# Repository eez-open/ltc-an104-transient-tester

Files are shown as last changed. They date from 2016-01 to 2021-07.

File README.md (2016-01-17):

LTC [AN104](http://www.linear.com/docs/29876) Closed loop load transient tester Eagle, Gebgers and BOM. It could be used for testing various LDOs, power supplies, etc.
Two PCB variants are available: 

* with power supply (ac-powered) that can be housed e.g. into Hammond diecast aluminium enclosure HM-1590U 
* without power supply (dc-powered) using two external 15 VDC sources connected with 2.1/5.5 mm DC plugs.

**Please note that max. allowed D.U.T voltage is determined with switching transistor SOA.**

**********************

Repository: www.github.com/eez-open
Web site: www.envox.hr/eez

**********************

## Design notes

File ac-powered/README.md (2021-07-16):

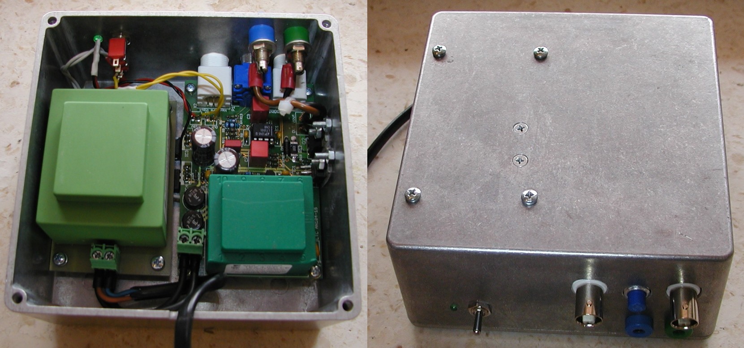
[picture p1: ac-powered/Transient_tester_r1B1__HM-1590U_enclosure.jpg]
Transient tester assembled


LTC [AN104](https://www.analog.com/media/en/technical-documentation/application-notes/an104f.pdf) Closed loop load transient tester (with on board power supply) 

**Please note that max. allowed D.U.T voltage is determined with switching transistor SOA.**

**********************

Repository: www.github.com/eez-open
Web site: www.envox.hr/eez

**********************

*EEZ 2-layer (+tKeepout +_tNames) *job script is used for generating Gerber files. Use [gerbv](http://gerbv.geda-project.org/), a free/open source Gerber viewer to inspect generated files.

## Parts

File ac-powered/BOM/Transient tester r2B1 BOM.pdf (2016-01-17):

LTC AN104 closed loop load transient tester with power supply (PCB: r2B1, 2016-10-16)

1,305
Farnell | TME
2 | B125R-DIO | | B1, B2 | 1861434 | 0,227 | £0,45 | B125R-DIO | 0,157 | 0,31 € | 0,31 €
4 | 100n | | C1, C2, C4, C5 | 1141777 | 0,072 | £0,29 | CM-100N-X7R | 0,038 | 0,15 € | 0,15 €
2 | 1u | | C3, C7 | 2112910 | 0,186 | £0,37 | C340C105K1R5TA | 0,214 | 0,43 € | 0,43 €
1 | 10n | | C6 | 1005991 | 0,556 | £0,56 | FKS2-10N/100 | 0,079 | 0,08 € | 0,08 €
2 | 1mF/25V | | C8, C11 | 1800654 | 0,368 | £0,74 | RD1E108M10020BB | 0,161 | 0,32 € | 0,32 €
2 | 1u | | C9, C10 | 1890147 | 1,080 | £2,16 | MKS2-1U/100-R | 0,228 | 0,46 € | 0,46 €
3 | SB1100 | | D1, D2, D3 | 1651106 | 0,404 | £1,21 | SB1100 | 0,047 | 0,14 € | 0,14 €
1 | LX008-V2 (80mA) | | F1 | 1175832 | 0,395 | £0,40 | LX008-V2 | 0,223 | 0,22 € | 0,22 €
1 | LT1210 | | IC1 | 1663394 | 9,272 | £9,27 | LT1210CT7 | 12,250 | 12,25 € | 12,10 €
1 | LT1001 | | IC2 | 2211376 | 2,922 | £2,92 | LT1001CN8 | 3,340 | 3,34 € | 3,34 €
1 | LM317 | | IC3 | 1652293 | 0,300 | £0,30 | LM317T-DG | 0,226 | 0,23 € | 0,23 €
1 | LM337 | | IC4 | 1211104 | 0,605 | £0,61 | LM337T-FAI | 0,315 | 0,32 € | 0,32 €
1 | 1K | | P1 | 9357734 | 4,440 | £4,44 | 91A1A-B28-B10L | 3,670 | 3,67 € | 3,67 €
1 | VN2222 | | Q1 | 9556834 | 0,322 | £0,32 | VN2222LL-G | 0,310 | 0,31 € | 0,31 €
1 | D44H11 | | Q2 | 2453343 | 0,538 | £0,54 | D44H11 | 0,480 | 0,48 € | 0,48 €
| MJE15030 | (Q2 alternative) | | 9557091 | 1,290 | | MJE15030G | 0,960
1 | 2K | R-EU_0204/5 | R1 | 9342788 | 0,052 | £0,05 | M0.4W-2K | 0,010 | 0,01 € | 0,01 €
1 | 560R | R-EU_0204/5 | R10 | 9343350 | 0,052 | £0,05 | M0.4W-560R | 0,010 | 0,01 € | 0,01 €
1 | 0R1 | 2512 | R12 | 2470947 | 0,887 | £0,89 | RL73K3AR10J | 0,180 | 0,18 € | 0,18 €
1 | 10R | | R13 | 9342443 | 0,052 | £0,05 | M0.4W-10R | 0,010 | 0,01 € | 0,01 €
2 | 200R | | R16, R19 | 9342770 | 0,051 | £0,10 | M0.4W-200R | 0,010 | 0,02 € | 0,02 €
2 | 2K2 | | R17, R18 | 9342834 | 0,053 | £0,11 | M0.4W-2K2 | 0,010 | 0,02 € | 0,02 €
1 | 1M | | R2 | 9342435 | 0,051 | £0,05 | M0.4W-1M | 0,010 | 0,01 € | 0,01 €
2 | 909R | | R3, R6 | 9470549 | 0,061 | £0,12 | - | | | 0,16 €
1 | 51R | | R4 | 9343342 | 0,051 | £0,05 | M0.4W-51R | 0,010 | 0,01 € | 0,01 €
2 | 100R | | R5, R11 | 9342397 | 0,052 | £0,10 | M0.4W-100R | 0,010 | 0,02 € | 0,02 €
4 | 10K | R7, R9, R14, R15 9342419 | 0,052 | £0,21 | M0.4W-10K | 0,010 | 0,04 € | 0,04 €
1 | 13K | | R8 | 9342583 | 0,052 | £0,05 | M0.4W-13K | 0,010 | 0,01 € | 0,01 €
1 | 18VAC/16VA | | TR1 | 1689097 | 6,150 | £6,15 | TEZ16/D/18V | 4,370 | 4,37 € | 4,37 €
1 | 18VAC/4VA | | TR2 | 1689077 | 2,800 | £2,80 | TEZ4/D/18V | 2,540 | 2,54 € | 2,54 €
2 | | 22-23-2021 | X1, X6 | 1462926 | 0,040 | £0,08 | MX-22-23-2021 | 0,060 | 0,12 € | 0,10 €
1 | | 1-227161-0 | X2 | 1704337 | 1,870 | £1,87 | 1-1337542-0 | 1,180 | 1,18 € | 1,18 €
2 | | | X3, X5 | 1793678 | 0,627 | £1,25 | 282836-5 | 0,770 | 1,54 € | 1,54 €
1 | 15V | ZENER-DIODE | ZD1 | 1779207 | 0,040 | £0,04 | BZX55C15-TAP | 0,019 | 0,02 € | 0,02 €
| | | | | | £38,61 | | | 32,81 € | 32,81 €

GBP/EUR ratio:

Qty | Value | Note | Parts | Code | Unit price | Total | Code | Unit price | Total | Combined
| | 2A bridge rectifier

(or 2N7000)

2-pin 0.1” socket
BNC coax jack
Terminal block 5-way,
1.5mm2, 5mm

LTC AN104 closed loop load transient tester with power supply (PCB: r2B1, 2016-10-16)

1 | | | 930027 | 9,230 | £9,23 | HM-1550C | 12,38 € | 12,38 € | 12,05 €
1 | | | 1698951 | 0,433 | £0,43 | PJ3230-B | 0,631 | 0,63 € | 0,57 €
1 | Red | | 1698950 | 0,462 | £0,46 | PJ3230-R | 0,631 | 0,63 € | 0,60 €
1 | 1-227161-0 | X4 | 1704337 | 1,870 | £1,87 | 1-1337542-0 | 1,180 | 1,18 € | 1,18 €

Enclosure
Hammond 1590U
Socket; 4mm banana Black
Socket; 4mm banana

Optional
BNC coax jack
File repository: | https://github.com/eez-open

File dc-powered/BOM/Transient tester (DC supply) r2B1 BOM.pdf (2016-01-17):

LTC AN104 closed loop load transient tester (PCB: r2B1, 2016-10-16)

1,305
Farnell | TME
2 | 1u | | C1, C9 | 2112910 | 0,186 | £0,37 | C340C105K1R5TA | 0,214 | 0,43 € | 0,43 €
2 | 47u/25v | | C2, C8 | | | £0,00 | ECA1JM470 | 0,127 | 0,25 € | 0,00 €
4 | 100n | | C3, C4, C6, C7 | 1141777 | 0,072 | £0,29 | CM-100N-X7R | 0,038 | 0,15 € | 0,15 €
1 | 10n | | C5 | 1005991 | 0,556 | £0,56 | FKS2-10N/100 | 0,079 | 0,08 € | 0,08 €
2 | 1mF/25V | | C8, C11 | 1800654 | 0,368 | £0,74 | RD1E108M10020BB | 0,161 | 0,32 € | 0,32 €
2 | 1u | | C9, C10 | 1890147 | 1,080 | £2,16 | MKS2-1U/100-R | 0,228 | 0,46 € | 0,46 €
1 | SB1100 | | D1 | 1651106 | 0,404 | £0,40 | SB1100 | 0,047 | 0,05 € | 0,05 €
1 | LT1210 | | IC1 | 1663394 | 9,272 | £9,27 | LT1210CT7 | 12,250 | 12,25 € | 12,10 €
1 | LT1001 | | IC2 | 2211376 | 2,922 | £2,92 | LT1001CN8 | 3,340 | 3,34 € | 3,34 €
1 | 1K | | P1 | 9357734 | 4,440 | £4,44 | 91A1A-B28-B10L | 3,670 | 3,67 € | 3,67 €
1 | VN2222 | | Q1 | 9556834 | 0,322 | £0,32 | VN2222LL-G | 0,310 | 0,31 € | 0,31 €
1 | D44H11 | | Q2 | 2453343 | 0,538 | £0,54 | D44H11 | 0,480 | 0,48 € | 0,48 €
| MJE15030 | (Q2 alternative) | | 9557091 | 1,290 | | MJE15030G | 0,960
1 | 2K | R-EU_0204/5 | R1 | 9342788 | 0,052 | £0,05 | M0.4W-2K | 0,010 | 0,01 € | 0,01 €
1 | 560R | R-EU_0204/5 | R10 | 9343350 | 0,052 | £0,05 | M0.4W-560R | 0,010 | 0,01 € | 0,01 €
1 | 0R1 | 2512 R12 | 2470947 | 0,887 | £0,89 | RL73K3AR10J | 0,180 | 0,18 € | 0,18 €
1 | 10R | | R13 | 9342443 | 0,052 | £0,05 | M0.4W-10R | 0,010 | 0,01 € | 0,01 €
2 | 200R | | R16, R19 | 9342770 | 0,051 | £0,10 | M0.4W-200R | 0,010 | 0,02 € | 0,02 €
2 | 2K2 | | R17, R18 | 9342834 | 0,053 | £0,11 | M0.4W-2K2 | 0,010 | 0,02 € | 0,02 €
1 | 1M | | R2 | 9342435 | 0,051 | £0,05 | M0.4W-1M | 0,010 | 0,01 € | 0,01 €
2 | 909R | | R3, R6 | 9470549 | 0,061 | £0,12 | - | | | 0,16 €
1 | 51R | | R4 | 9343342 | 0,051 | £0,05 | M0.4W-51R | 0,010 | 0,01 € | 0,01 €
2 | 100R | | R5, R11 | 9342397 | 0,052 | £0,10 | M0.4W-100R | 0,010 | 0,02 € | 0,02 €
4 | 10K | R7, R9, R14, R15 9342419 | 0,052 | £0,21 | M0.4W-10K | 0,010 | 0,04 € | 0,04 €
1 | 13K | | R8 | 9342583 | 0,052 | £0,05 | M0.4W-13K | 0,010 | 0,01 € | 0,01 €
2 | | 22-23-2021 | X1, X5 | 1462926 | 0,040 | £0,08 | MX-22-23-2021 | 0,060 | 0,12 € | 0,10 €
1 | | 1-227161-0 | X2 | 1704337 | 1,870 | £1,87 | 1-1337542-0 | 1,180 | 1,18 € | 1,18 €
1 | | | X3 | 1793678 | 0,627 | £0,63 | 282836-5 | 0,770 | 0,77 € | 0,77 €
2 | | 2.1mm/5.5mm | X4, X7 | 1217037 | 0,703 | £1,41 | PC-GK2.1 | 0,159 | 0,32 € | 0,32 €
1 | 15V | ZENER-DIODE | ZD1 | 1779207 | 0,040 | £0,04 | BZX55C15-TAP | 0,019 | 0,02 € | 0,02 €
| | | | | | £27,87 | | | 24,53 € | 24,27 €
1 | | 1-227161-0 | X6 | 1704337 | 1,870 | £1,87 | 1-1337542-0 | 1,180 | 1,18 € | 1,18 €

GBP/EUR ratio:

Qty | Value | Note | Parts | Code | Unit price | Total | Code | Unit price | Total | Combined

(or 2N7000)

2-pin 0.1” socket
BNC coax jack
Terminal block 5-way,
1.5mm2, 5mm
DC male socket

Optional
BNC coax jack
File repository: | https://github.com/eez-open

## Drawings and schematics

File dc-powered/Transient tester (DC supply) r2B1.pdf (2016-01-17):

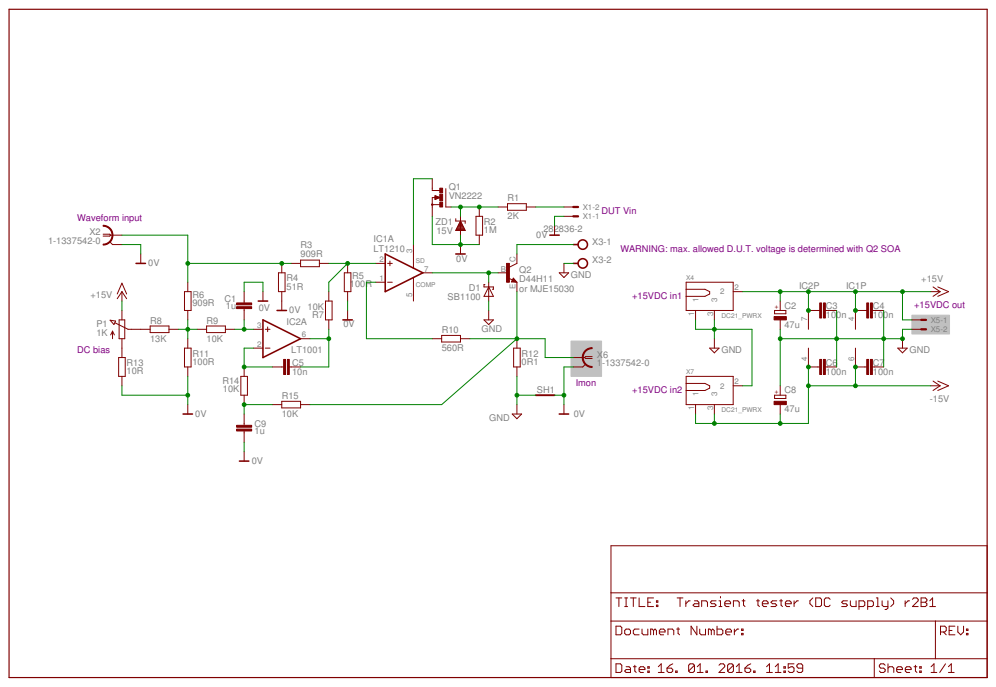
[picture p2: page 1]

WARNING: max. allowed D.U.T. voltage is determined with Q2 SOA
GND

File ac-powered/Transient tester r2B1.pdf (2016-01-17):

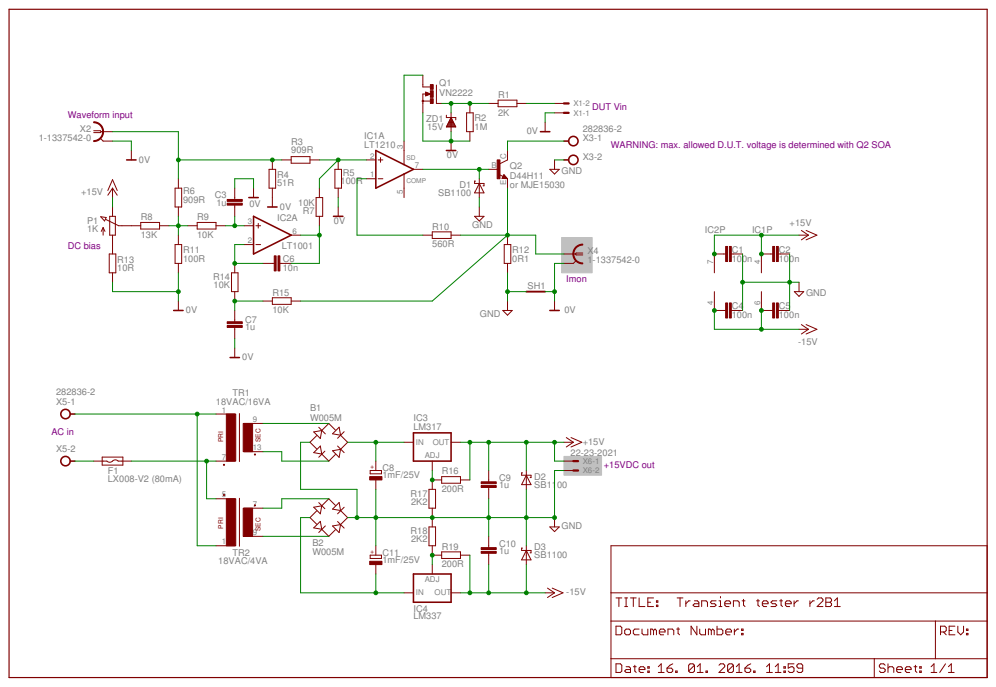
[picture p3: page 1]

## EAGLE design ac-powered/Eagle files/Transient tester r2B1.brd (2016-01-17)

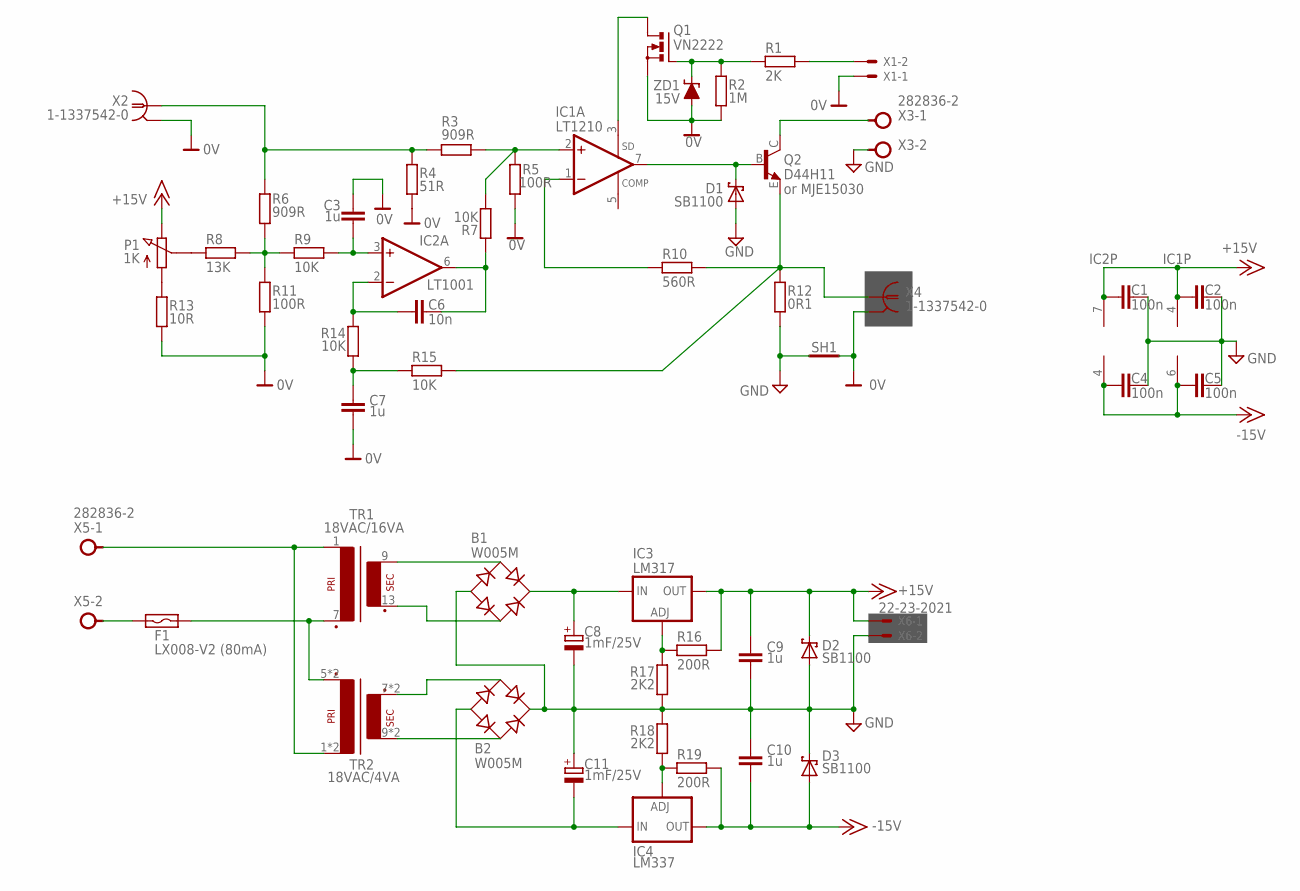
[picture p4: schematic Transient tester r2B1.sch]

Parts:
B1, B2: W005M; RB1A
C1, C2, C4, C5: 100n; C050-025X075
C3, C7: 1u; C050-075X075
C6: 10n; C050-025X075
C8, C11: 1mF/25V; ECAP5/10.5
C9, C10: 1u; C050-025X075
D1, D2, D3: SB1100; DO34/10
F1: LX008-V2 (80mA); POLYSWITCH-R7
IC1: LT1210; TO220-7
IC2: LT1001; DIL08D
IC3: LM317; 317TS
IC4: LM337; 337TS
P1: 1K; BOURNS_POT91
Q1: VN2222; TO92-SGD
Q2: D44H11; TO220BV
R1: 2K; 0204/5
R2: 1M; 0204/5
R3, R6: 909R; 0207/10
R4: 51R; 0204/5
R5, R11: 100R; 0204/5
R7, R9, R14, R15: 10K; 0204/5
R8: 13K; 0204/5
R10: 560R; 0204/5
R12: 0R1; OAR1+2512
R13: 10R; 0204/5
R16, R19: 200R; 0204/5
R17, R18: 2K2; 0204/5
SH1: SHORTH; SHORT_2
TR1: 18VAC/16VA; PCB_TRAFO16VA
TR2: 18VAC/4VA; PCB_TRAFO_4VA
X1: 22-23-2021
X2, X4: 1-1337542-0; AMP_227161
X3, X5: 282836-2; TBLOCK5.0_2
X6: 22-23-2021; MPN 22-23-2021
ZD1: 15V; DO34-ZD

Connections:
0V: C3.1, C7.2, Q1.S, R2.1, R4.1, R5.2, R11.1, R13.1, SH1.2 (GND_B), X1.1, X2.2 (GND), X4.2 (GND), ZD1.A
+15V: C1.2, C2.2, C9.1, D2.C, IC1.4 (V+), IC2.7 (V+), IC3.2 (OUT), P1.1 (E), R16.2, X6.1
-15V: C4.2, C5.2, C10.2, D3.A, IC1.6 (V-), IC2.4 (V-), IC4.3 (OUT), R19.2
GND: B1.-, B2.+, C1.1, C2.1, C4.1, C5.1, C8.-, C9.2, C10.1, C11.+, D1.A, D2.A, D3.C, R12.1, R12.1.1 (1), R17.2, R18.1, SH1.1 (GND_A), X3.2, X6.2
IN2: TR1.1, TR2.1, TR2.1.1 (P1), X5.1
unnamed: IC1.1 (-IN), R10.2
unnamed: Q2.E, R10.1, R12.2, R12.2.1 (2), R15.2, X4.1
unnamed: IC1.3 (SD), Q1.D
unnamed: Q1.G, R1.2, R2.2, ZD1.C
unnamed: D1.C, IC1.7 (OUT), Q2.B
unnamed: IC1.2 (+IN), R3.2, R5.1, R7.1
unnamed: C6.1, IC2.6 (OUT), R7.2
unnamed: C6.2, IC2.2 (-IN), R14.1
unnamed: C7.1, R14.2, R15.1
unnamed: P1.2 (S), R8.2
unnamed: P1.3 (A), R13.2
unnamed: R6.1, R8.1, R9.1, R11.2
unnamed: C3.2, IC2.3 (+IN), R9.2
unnamed: R3.1, R4.2, R6.2, X2.1
unnamed: B1.AC1, TR1.13 (S2)
unnamed: Q2.C, X3.1
unnamed: IC4.1 (ADJ), R18.2, R19.1
unnamed: F1.P$1 (1), X5.2
unnamed: B1.AC2, TR1.9 (S1)
unnamed: B2.AC1, TR2.7 (S2), TR2.7.1 (S2)
unnamed: B2.-, C11.-, IC4.2 (IN)
unnamed: IC3.1 (ADJ), R16.1, R17.1
unnamed: B2.AC2, TR2.9 (S1), TR2.9.1 (S1)
unnamed: R1.1, X1.2
unnamed: F1.P$2 (2), TR1.7 (P2), TR2.5 (P2), TR2.5.1 (P2)
unnamed: B1.+, C8.+, IC3.3 (IN)

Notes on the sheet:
or MJE15030

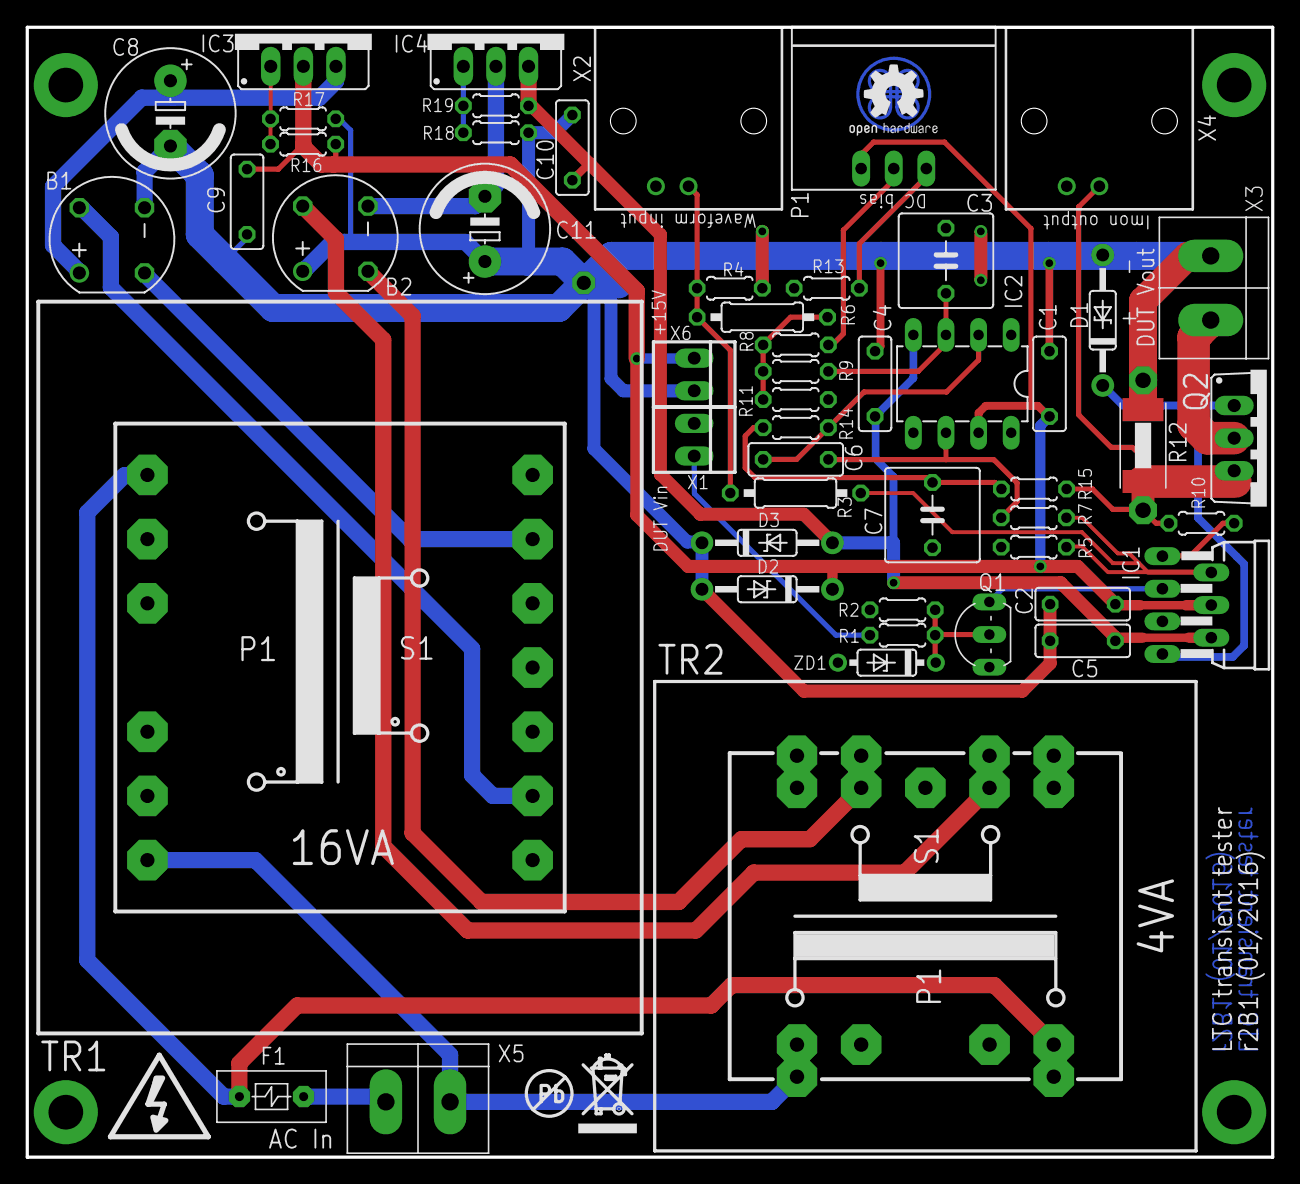
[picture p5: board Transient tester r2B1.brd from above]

Board: 2 copper layers, 97.0 x 88.0 mm, 57 parts (0 on the bottom side), 31 nets.

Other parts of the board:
EEZ_SIGNATURE1: SIGNATURESMALL; SIGNATURE_5MM
GOLD_ORB_SM: OSHWLOGO_GOLD_ORB_SM; OSHW2
U$2: RECYCLE_BIN1/8
U$3: PB_SMALL

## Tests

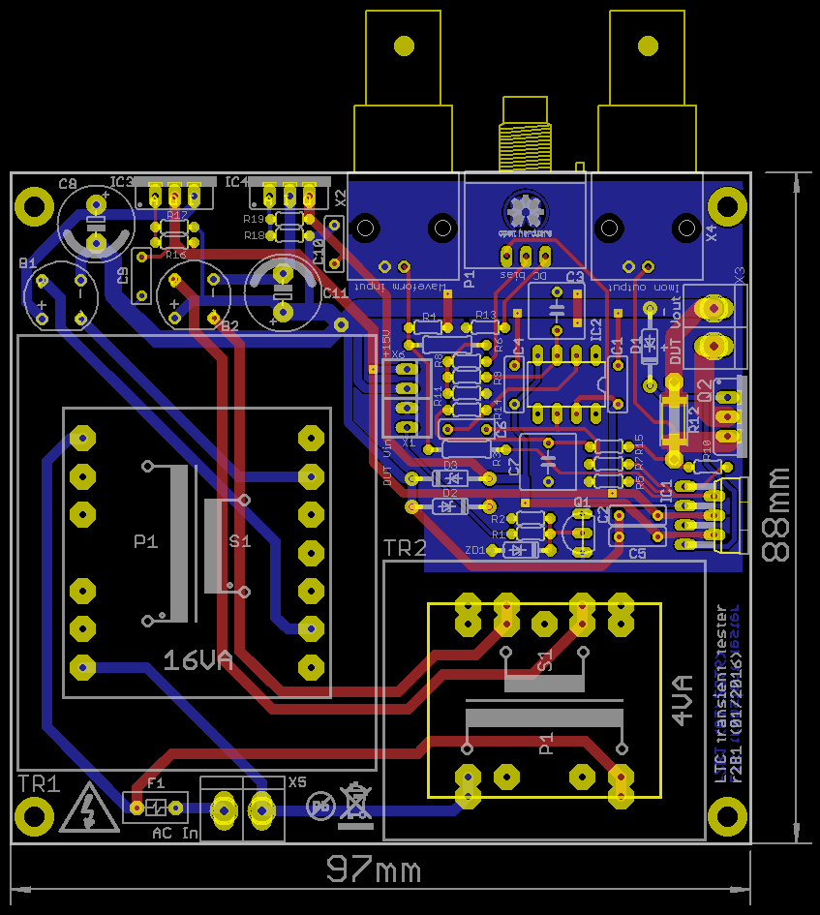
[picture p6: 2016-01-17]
ac-powered/Transient tester r2B1 (all).png

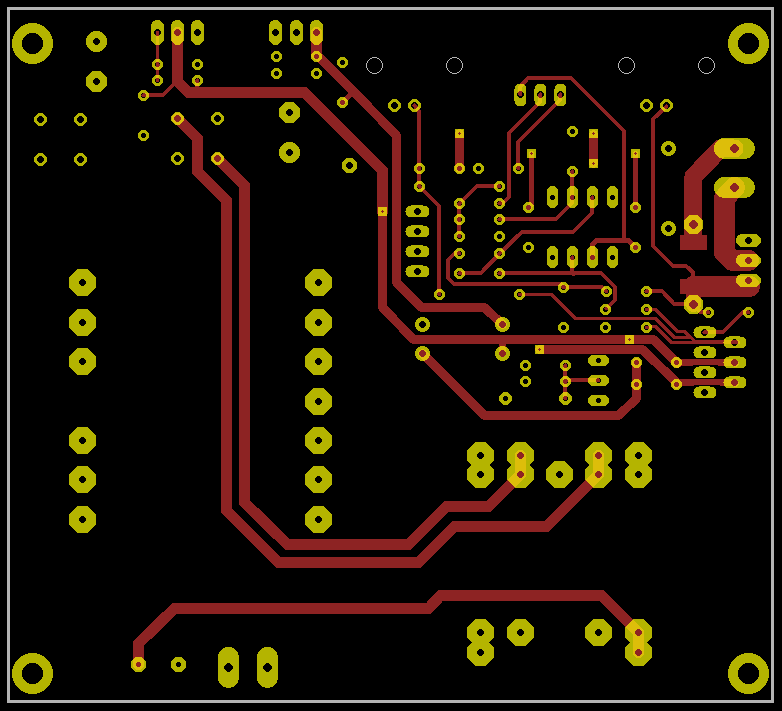
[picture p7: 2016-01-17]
ac-powered/Transient tester r2B1 (top).png

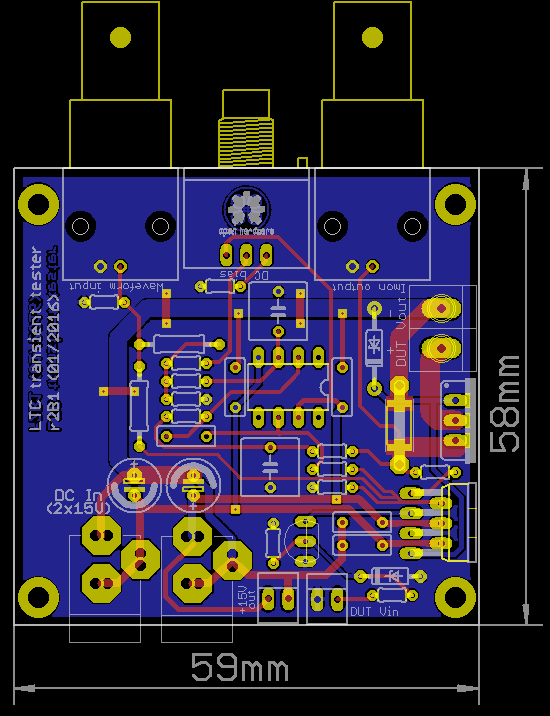
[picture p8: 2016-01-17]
dc-powered/Transient tester (DC supply) r2B1 (all).png

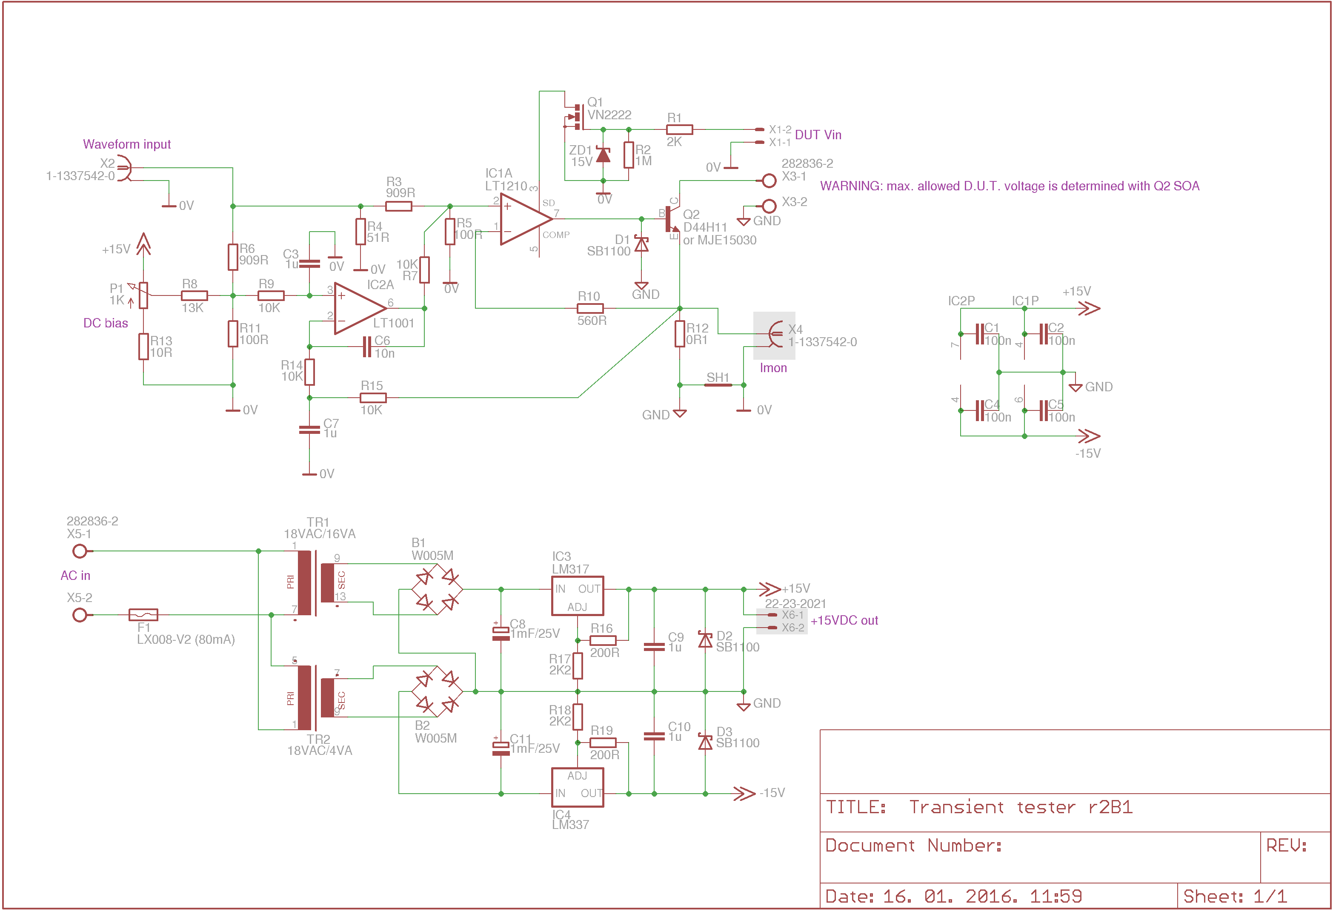
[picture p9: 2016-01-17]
ac-powered/Transient tester r2B1 Sheet1of1.png

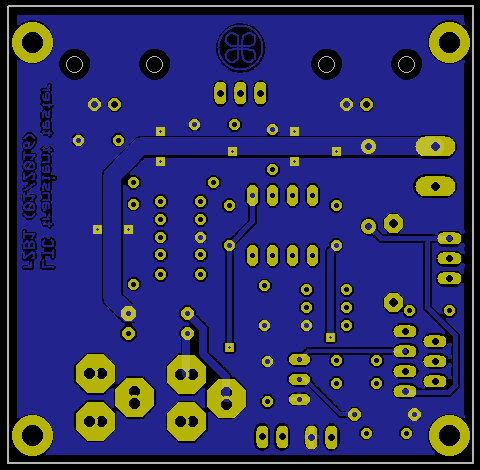
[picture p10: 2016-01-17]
dc-powered/Transient tester (DC supply) r2B1 (bottom).png

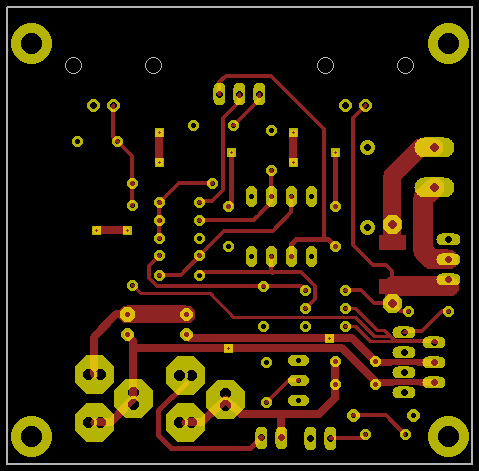
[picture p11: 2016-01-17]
dc-powered/Transient tester (DC supply) r2B1 (top).png

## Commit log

2016-01-17 enclosure name corrected
    [Transient tester r2B1 BOM.ods]
2021-07-16 Links updated
    [Transient tester (DC supply) r2B1 BOM.ods, Transient tester (DC supply) r2B1.brd, Transient tester (DC supply) r2B1.sch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]

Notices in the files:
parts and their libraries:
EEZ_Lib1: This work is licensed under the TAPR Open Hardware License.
